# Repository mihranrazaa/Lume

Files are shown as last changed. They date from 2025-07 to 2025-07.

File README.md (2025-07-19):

# Lume

An Open Source alternative of Kindle which gives you freedom to download and read anything you want.

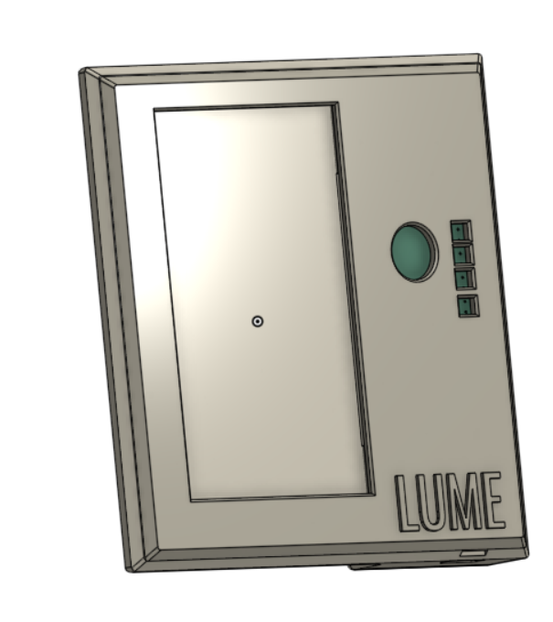
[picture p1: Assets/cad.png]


----

## Overview 

Lume is a open source eBook Reader made for people who value freedom, simplicity and are fed up by the limitations and companies not valuing ownership . With Lume, you're free to choose how you read and what you install.

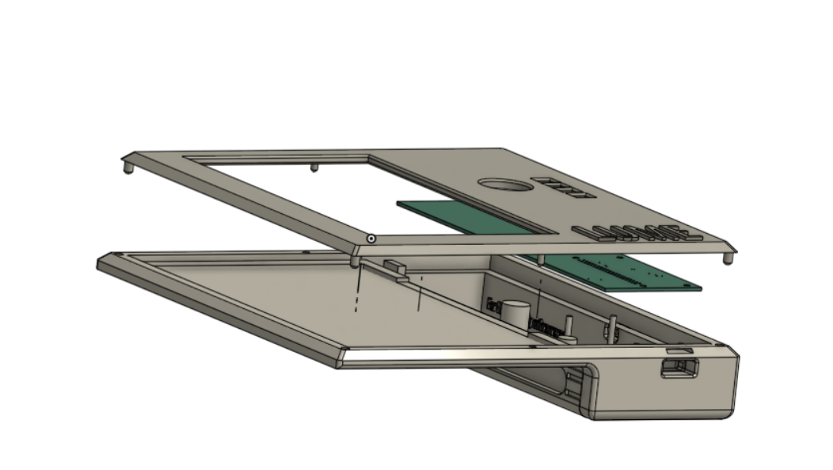
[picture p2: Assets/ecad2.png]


---

## Specifications
### Features(V0.1)

- Simple Menu System
- Bookmark System
- Joystick for smooth navigation
- Reading files ofc
- Offline-First
- approx1 week battery life (on medium usage)

### Hardware Support

- 7.5inch E-ink display
- Raspberry PI Zero 2w
- 5 way joystick navigation
- 4 Push buttons

### Controls

- **Joystick : Navigate menu items
- **Joystick : Turn pages while reading
- **Joystick : Select item
- **Button 1 : Return to menu
- **Button 2 : Back/Return to menu
- **Button 3 : Bookmark current page
- **Button 4 : Settings

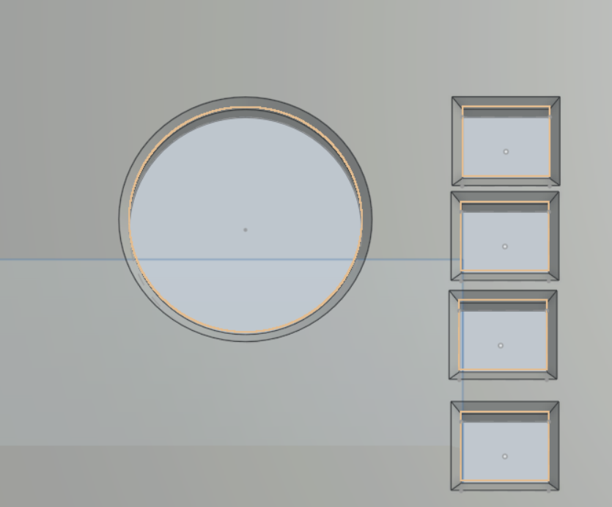
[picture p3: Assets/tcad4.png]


---
## Files to Build

### PCB

The files for the PCB and Schematics are available in the PCB folder and gerber files are added in the Production folder..

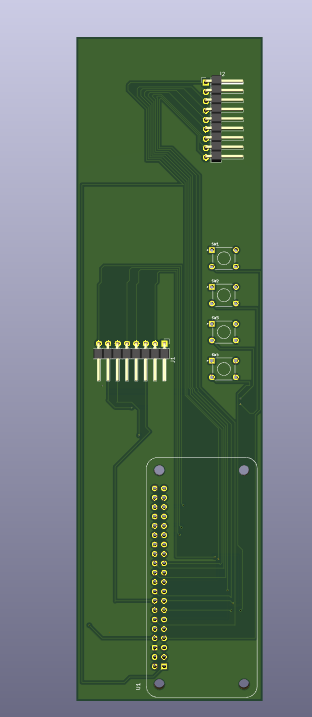
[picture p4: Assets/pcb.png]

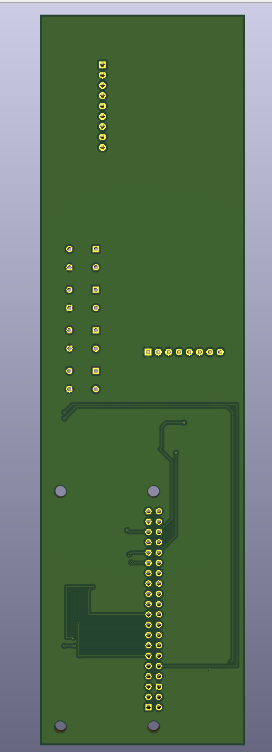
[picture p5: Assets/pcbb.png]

### 3D Case(CAD)

The step files for the keyboard are available in the CAD folder and also in the Production Folder.

**BASE**

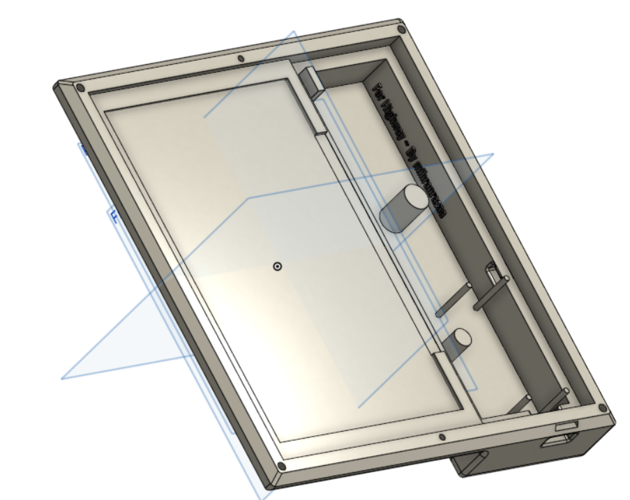
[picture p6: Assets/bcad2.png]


**PLATE**

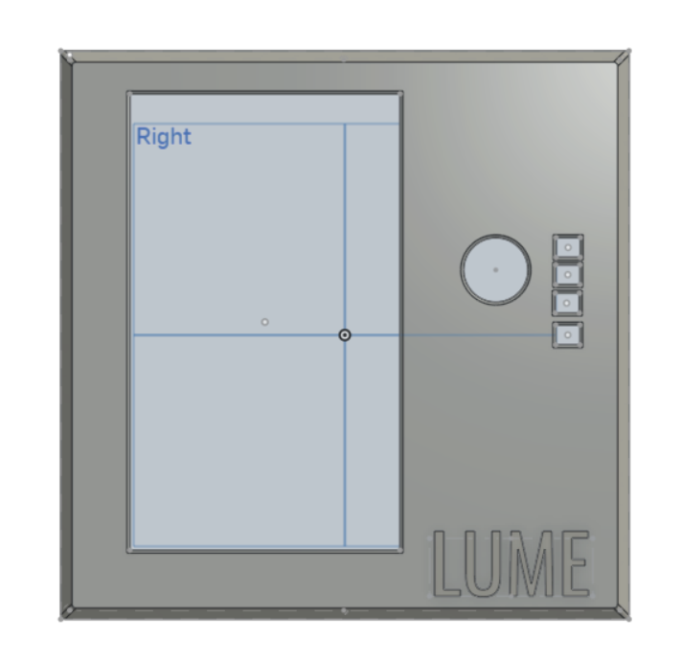
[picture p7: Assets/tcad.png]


---
## Images

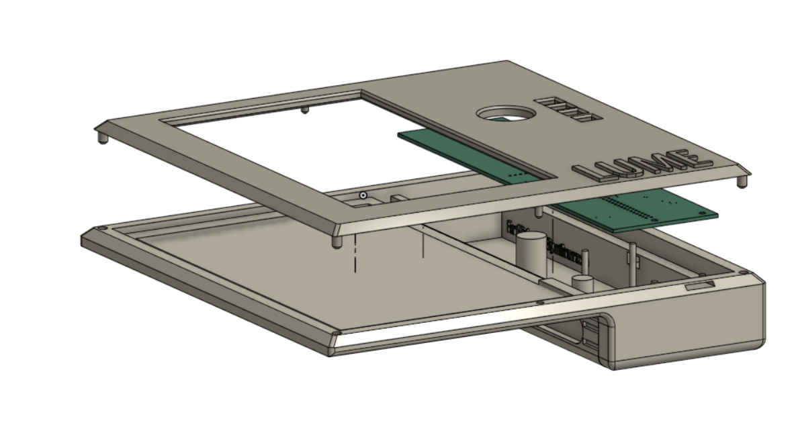
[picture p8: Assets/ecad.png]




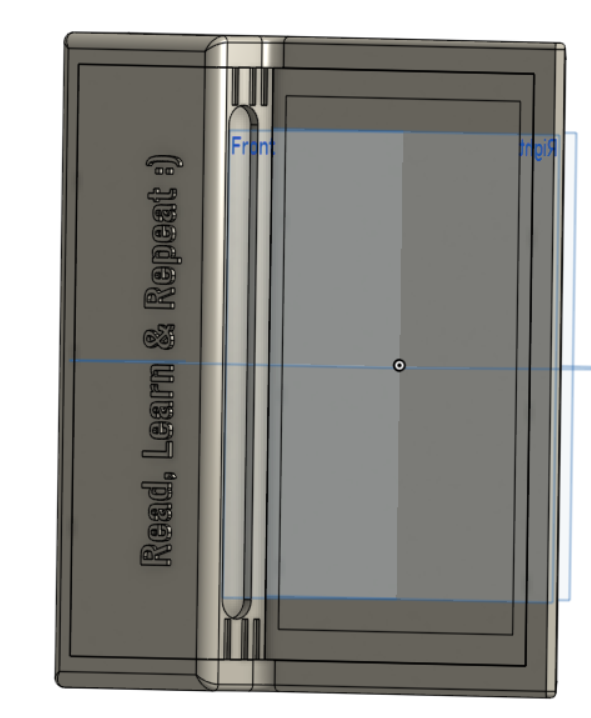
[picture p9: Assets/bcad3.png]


---
## BOM

| Components | Quantity | Price | Link |
| --- | --- | --- | --- |
| Raspberry pi zero 2w  | 1 | 16USD | [Available](https://www.fabtolab.com/raspberry-pi-zero-2-w-rp3a0-1ghz-quad-core-64-bit-arm-cortex-a53-cpu-512mb-sdram-wireless-lan-mini-hdmi-port-micro-usb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) |
| 7.5inch E-ink Display | 1 | 63USD | [Available](https://hubtronics.in/7-5-inch-e-paper-hat?search=7.5%20inch%20e%20ink%20) |
| 5D Joystick | 1 | 0.58USD | [Available](https://hubtronics.in/5d-rocker-joystick?search=joystick) |
| Tactile push buttons  | 4 | 0.28USD | |
| PCB | | approx10USD | |
| UPS | 1 | 27USD | [Available](https://hubtronics.in/ups-hat-c?search=ups%20hat%20) |
* Forgot to add an SD Card in there my bad

**Total ::  110-130USD**

---
## Next Update

- Add more support for different file types
- More Reading features
- Ability to transfer files via Wifi or Bluetooth 
- Progress bar

---
## Extra Stuff

### Gratitude
- Thanks to Hackclub for making me do this brilliant project, More coming :).
- Thanks to my potato for helping me till the end.
- Thanks to myself for completing the project and not getting distracted with another project.
- And Thank you for Reading?

### Inspiration
I always wanted a ebook reader and i was thinking of buying kindle but then got to know it's limitations so why not build my own :).

### Challanging
Building the custom case.. i don't have the words to express my pain...

---

## End
Check my [BLOG](https://mihranrazaa.pages.dev/)
~ mihranrazaa

BYEEE

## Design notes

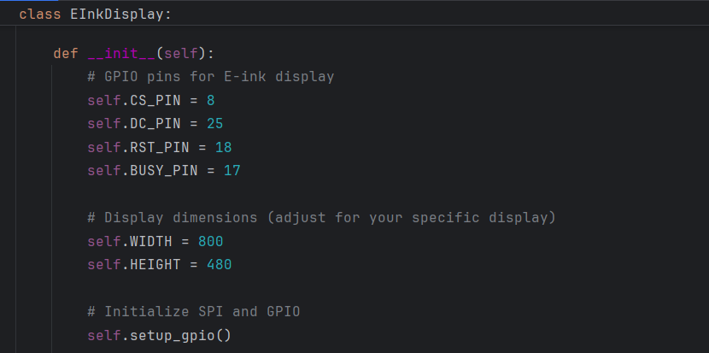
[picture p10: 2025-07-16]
Assets/code.png

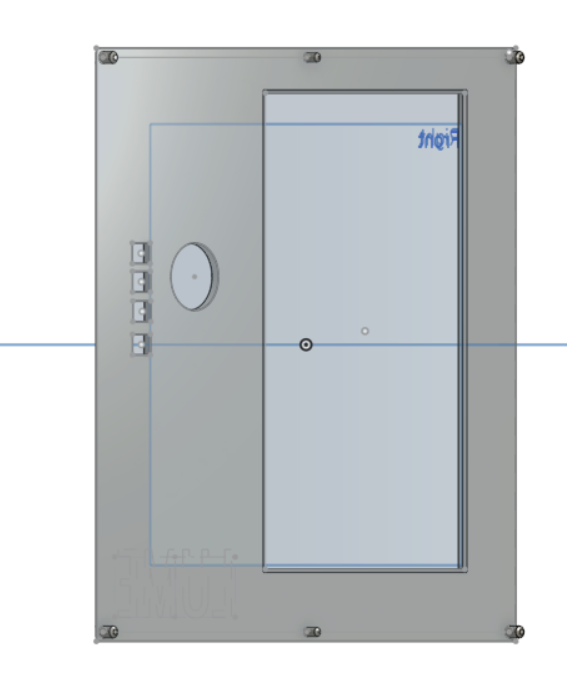
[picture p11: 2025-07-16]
Assets/tcad2.png

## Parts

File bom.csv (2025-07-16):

Designator | Footprint | Quantity | Value | LCSC Part #
J1 | PinHeader_1x08_P2.54mm_Horizontal | 1 | Conn_01x08
J2 | PinHeader_1x09_P2.54mm_Horizontal | 1 | Conn_01x09
SW1, SW2, SW3, SW4 | SW_1825910-6-43D | 4 | 1825910-6
U1 | MODULE_RASPBERRY_PI_ZERO_2_W | 1 | RASPBERRY_PI_ZERO_2_W

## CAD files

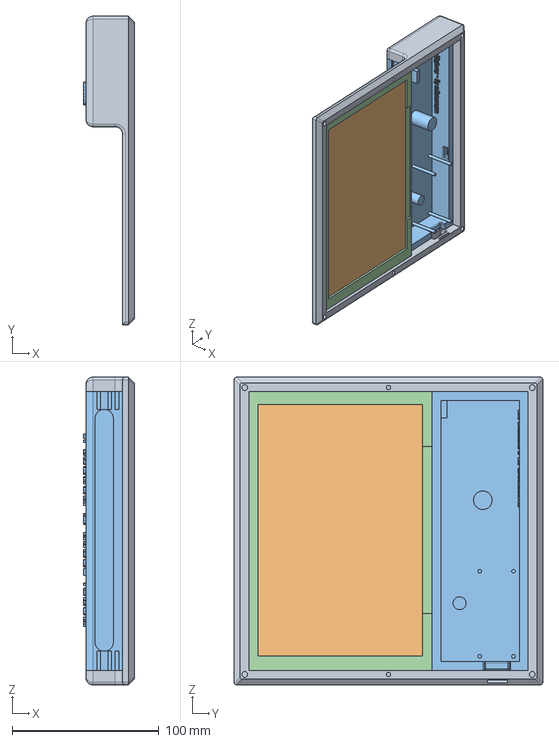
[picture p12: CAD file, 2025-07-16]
CAD/LUME-Base.step
34.5 x 210.5 x 210.0 mm

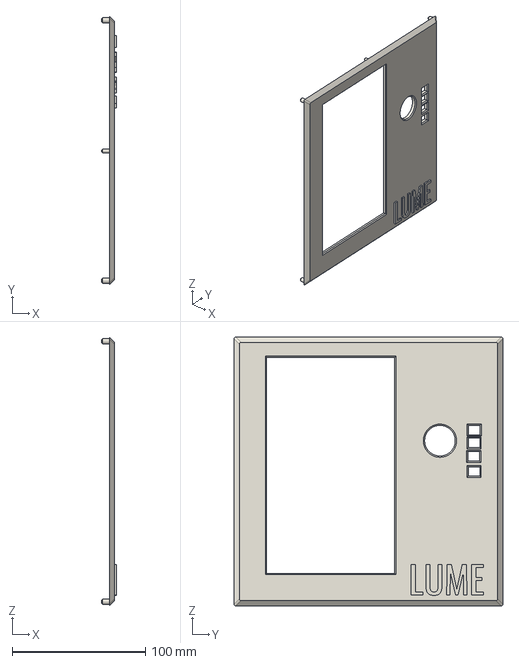
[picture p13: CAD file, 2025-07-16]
CAD/LUME-Top.step
11.5 x 201.7 x 201.7 mm

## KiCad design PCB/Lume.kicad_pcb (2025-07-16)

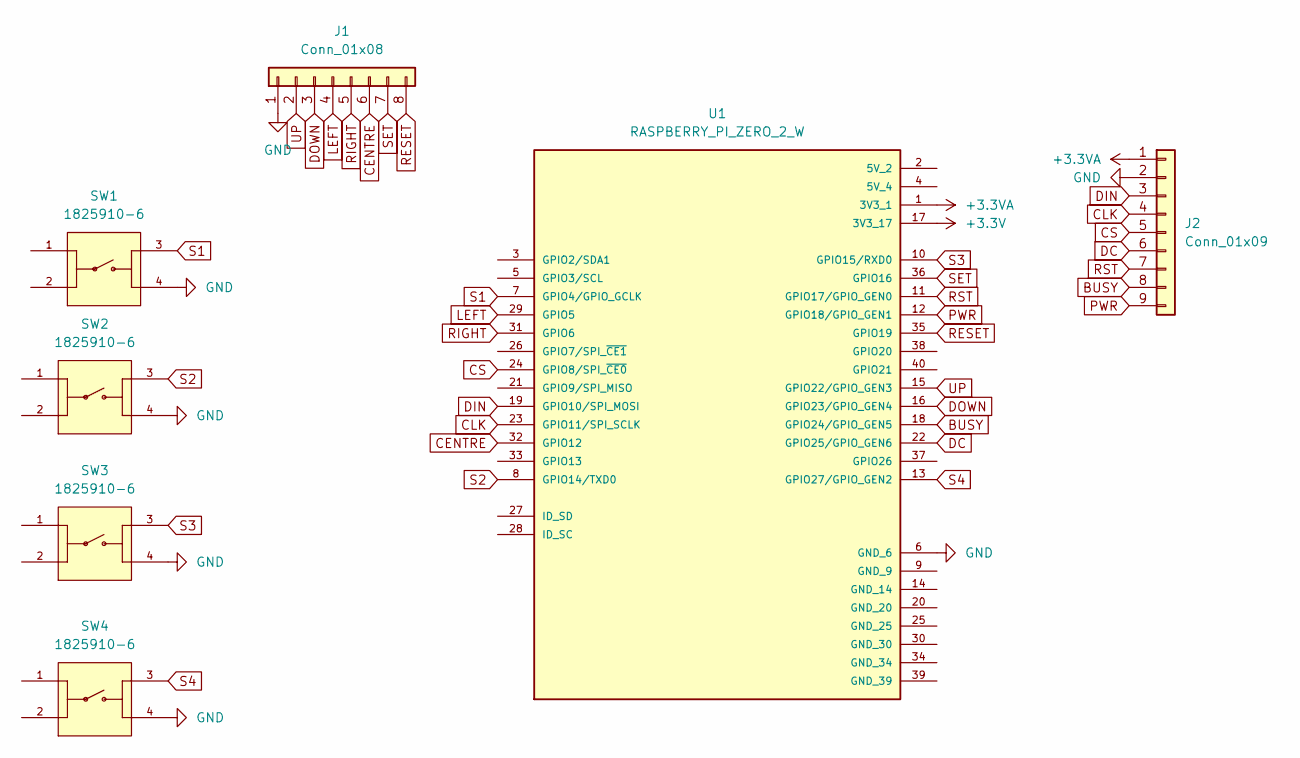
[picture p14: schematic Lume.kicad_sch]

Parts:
J1: Conn_01x08; PinHeader_1x08_P2.54mm_Horizontal
J2: Conn_01x09; PinHeader_1x09_P2.54mm_Horizontal
SW1, SW2, SW3, SW4: 1825910-6; SW_1825910-6-43D; PARTREV C10
U1: RASPBERRY_PI_ZERO_2_W; MODULE_RASPBERRY_PI_ZERO_2_W; PARTREV April 2024

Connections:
+3.3V: U1.17 (3V3_17)
+3.3VA: J2.1, U1.1 (3V3_1)
BUSY: J2.8, U1.18 (GPIO24/GPIO_GEN5)
CENTRE: J1.6, U1.32 (GPIO12)
CLK: J2.4, U1.23 (GPIO11/SPI_SCLK)
CS: J2.5, U1.24 (GPIO8/SPI_~CE0)
DC: J2.6, U1.22 (GPIO25/GPIO_GEN6)
DIN: J2.3, U1.19 (GPIO10/SPI_MOSI)
DOWN: J1.3, U1.16 (GPIO23/GPIO_GEN4)
GND: J1.1, J2.2, SW1.4, SW2.4, SW3.4, SW4.4, U1.6 (GND_6)
LEFT: J1.4, U1.29 (GPIO5)
PWR: J2.9, U1.12 (GPIO18/GPIO_GEN1)
RESET: J1.8, U1.35 (GPIO19)
RIGHT: J1.5, U1.31 (GPIO6)
RST: J2.7, U1.11 (GPIO17/GPIO_GEN0)
S1: SW1.3, U1.7 (GPIO4/GPIO_GCLK)
S2: SW2.3, U1.8 (GPIO14/TXD0)
S3: SW3.3, U1.10 (GPIO15/RXD0)
S4: SW4.3, U1.13 (GPIO27/GPIO_GEN2)
SET: J1.7, U1.36 (GPIO16)
UP: J1.2, U1.15 (GPIO22/GPIO_GEN3)

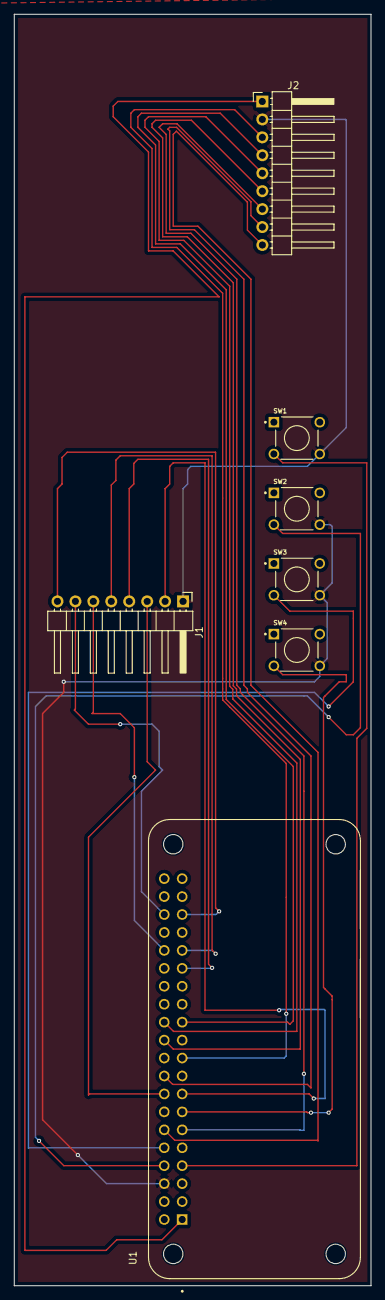
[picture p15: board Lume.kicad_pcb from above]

Board: 2 copper layers, 50.5 x 180.0 mm, 7 parts (0 on the bottom side), 20 nets.

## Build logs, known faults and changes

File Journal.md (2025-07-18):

---

title: "Lume"

author: "mihranrazaa"

description: "An Open Source alternative of Kindle "

created at: "2025-07-13"

---

----

**12 JULY**

- SO the plan is to build a alternative of kindle why? because from what i have seen on youtube, kindle can ban your account and your purchased books will be gone, sometimes when the deal between kindle and author of some book gets expired the books automatically vanishes from your account which is crazy, someone is paying full price but still he is not owning that piece, like it is not even a clooud service where subscription model is understandable.
- So yeah i thought to build a complete open source E book Reader "Lume" and this will be my first prototype...

---

**13 JULY**

- I have figured out my design i will make it, so today i first started by researching what components i will be using as i learnind in AMA if you are building a project which you want someone else to recreate use modules which is a good excuse to my lack of skills, so i selected Rpi zero 2w as my main MCU because it has wifi, blutooth and good support, i have a basic idea of what kind of software i want to build, so it is perfect for that, next i'm using 7.5inch e ink display with driver, vertically not horizontally which is giving more of real book page kind of vibe, then for inputs i first thought of five tactile push buttons for navigating and selecting but then i added a joystick and 4 tackile push buttons which will drastically improve user navigation as i'm building it for myself i think this will be a good choice so yeah also i will be using a battery hat for my pi zero 2w for poratbility ofc.....

- Alright so completed the schematics, i will be using 8pin cable to connect the driver to the main board, also i'm using 5D joystick because normal joystick module required ADC driver and i didn;t wanted to include it, and they both were same priced so i chose this, my idea of the CAD design is i can grab one side of the case with ease like it will be lifted from back and i will add pcb there, so yeah that works, now on to building pcb

- PCB DONEEE!!! so it is like a vertical strip, routing is good i have given adequate spacing for them so it should be fine, i enjoyed building this pcb lol, I've been working this whole day on this lol, i thought of this project yesterday and i now i have created it's PCB, Building is FUN. After coming back home i might start CAD let's see my plan is finishing this till 15th July....

- And yeah here are all the images:

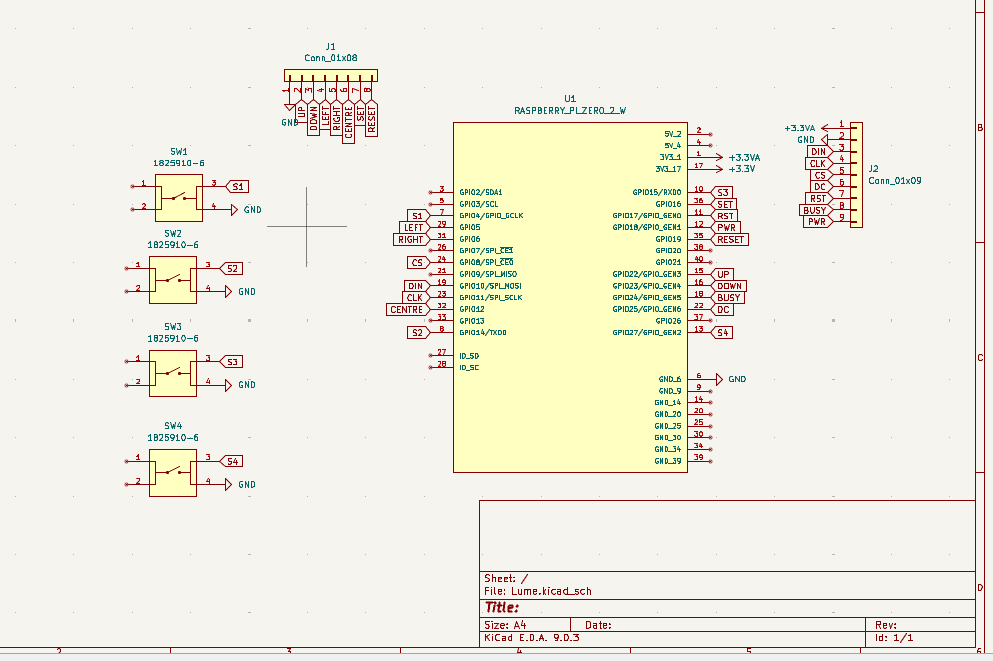
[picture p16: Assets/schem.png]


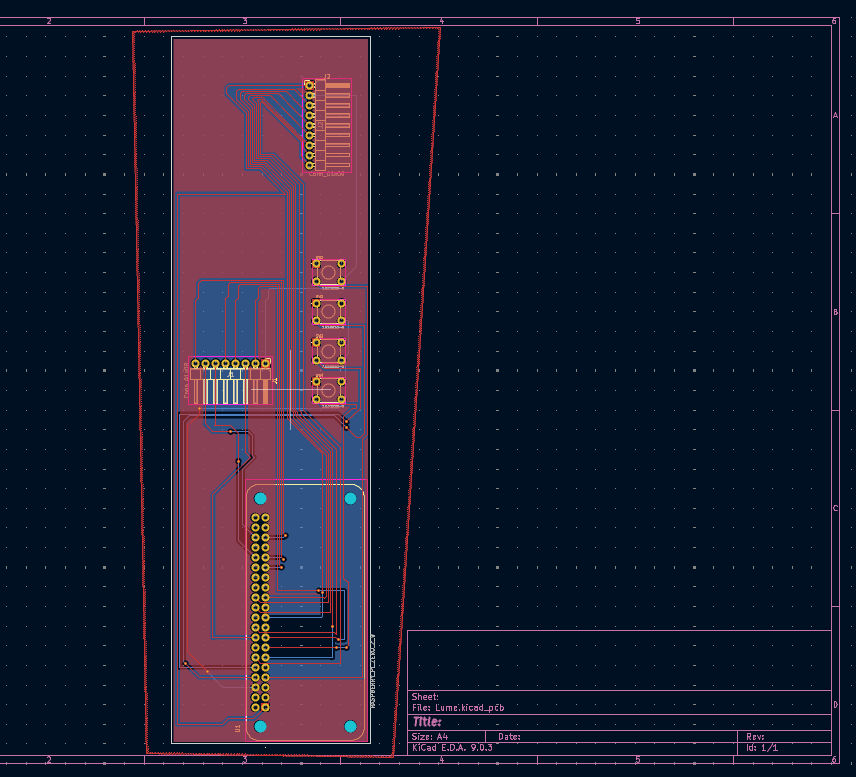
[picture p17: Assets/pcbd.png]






**Total 8Hrs+**

---

**14-15 JULY (CAD!!!!)**

- I forgot to write the Journal on 14th, i spent almost all day working on cad and didn't had energy to write journal lol, so this is the complete process of how i created my case.. I already had a basic idea in my mind, i didn't wanted to build a tab like reader so i searched some available reader and i found a very good concept basically there will be sleek display part and a elevated hardware part which will also work as grip to hold the reader, so i first start by taking mesurements of the display it is 7.5 inch display, so i already thought that i will rotat the display because it will look more like big book then that's why i created the pcb vertically rather then horizontal, so yeah,. That sums up the rough idea other things just came while doing it...

- I start by importing the pcb first to makesure the case fits in, i prefer to build over the components it give me confidence that the dimensions are coorect if i use a correct cad file lol, anyways then i created the rough sketch i first created them in one sketch but then i had to divide the base in 2-3 different parts as i'm noob and i was getting confused so it made easier to work with so i created the base extrusion nad basic stuff, then i started aligning and fixing the pcb place, i had to keep in mind that there will be a cable and driver board which will be connected in the pcb but there will also be wire from the display so i kept some gap so that wires can pass through, then i created the elevated part to which i used shell option in onshape, Then i thought becuase i was addding a grip olfring type thing why not add extrude inside where fingers will be placed for better grip, and it will also improve the look and it did!, so i added a cylindrical area in the elevated shell, then i added holes for my screwless design, i learned some more about snap fit designs and it is better to make the pins a bit bigger and add chaffer for enough friction, so i added 4mm and 3mm holes in the frame, Oh yeah i forgot to add that i added support for PCB and for pi zero 2 w and battery, then i started making it look good fixing small stuff checking dimensions, i added chaffer, fillet, also added more inside extrusion lines this time near the cylindrical holding area, then i added some writing in the case because why not.. Then i added 2 openings in the case, one for sd card and one for power, as i don't think it is needed any ports except power as there is only time that you have to add sd in pi zero and done filed will be uploaded via wifi or bluetooth, still because this is version 1 i did it anyways, with that my verision on ebase was ready and i moved to top...

- I started by taking dimensions of the main out frame i got confused a bit becuase of chaffer and fillet i was getting wrong dimensions i forgot about them then after realizing i fixed and it got write then added screen dimension and added input holes sketch oh yeah i forgot add thaat above anyways i put them in the correct place extruded the frame by 4-5mm then added chaffer and fillet, now when in assembly they are actually looking good, then i satrted taking dimesions of the holes and recreated that sketch in the the plate, added pin added chaffer, and pins were done, next i remved lume from back of base an added in the bottom of plate, after this the basic version was ready then i again touched up some parts and version 1 was ready.... checked if the pins are correctly ocnnecting or not and everything was fine, which leads us to right now i'm experimenting with colors i''m thinking of dark colour, and after this i have to start developing the code,i have to finish a alpha working code to ship it with the project i can work and improve the os with time...

- SO yeah that was the whole process of me building the case for Lume V1, ofc timelines are a bit different like not everything happend text by text i took breaks did other stuff returned worked on this and all, now i have to work on the code for this project, i have to shift the deadline to one more day, my previous goal was to ship the project on 15th july like a hackathon but it is isn't possible building the whole code in one day is not much possible for me i hope for the best....

- Here are all the images of building the CASE::

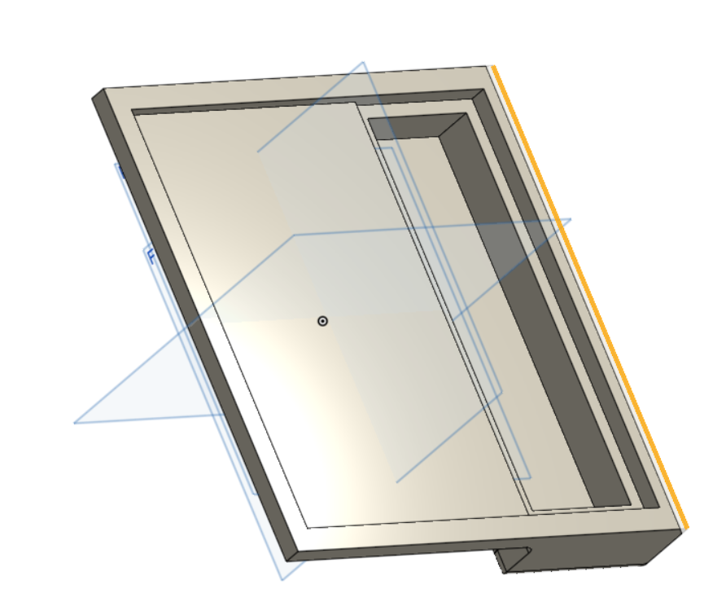
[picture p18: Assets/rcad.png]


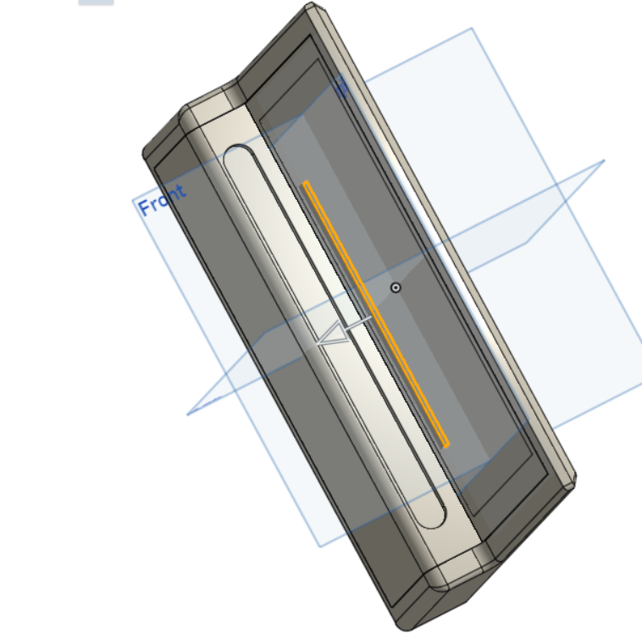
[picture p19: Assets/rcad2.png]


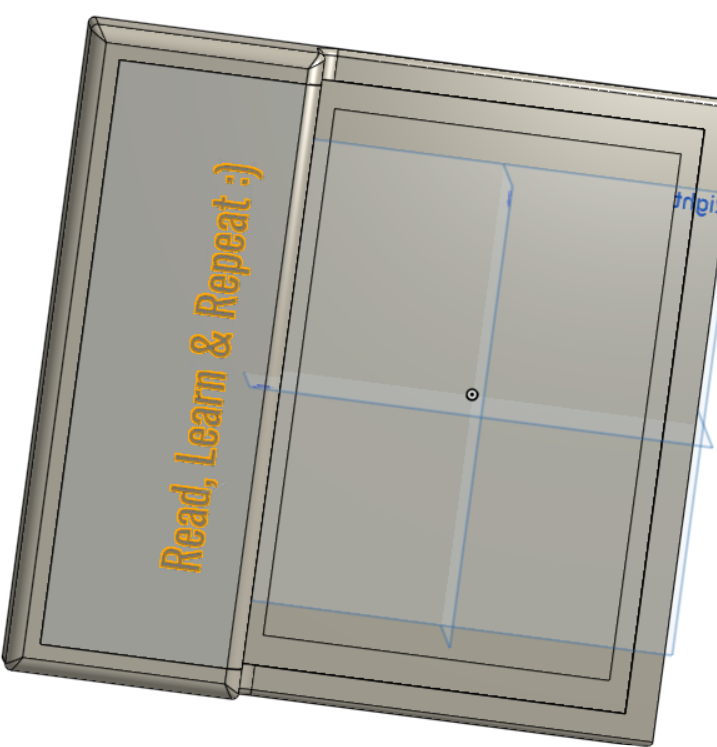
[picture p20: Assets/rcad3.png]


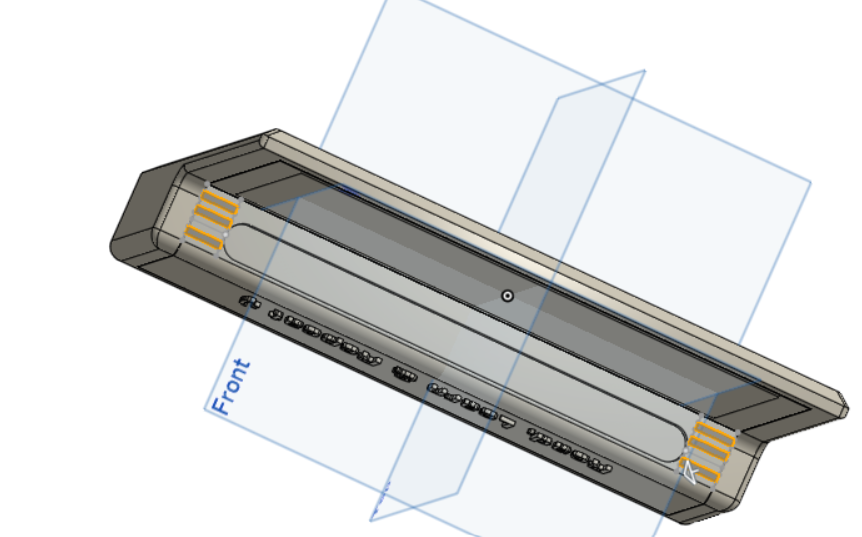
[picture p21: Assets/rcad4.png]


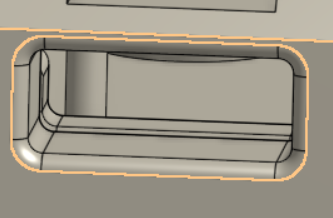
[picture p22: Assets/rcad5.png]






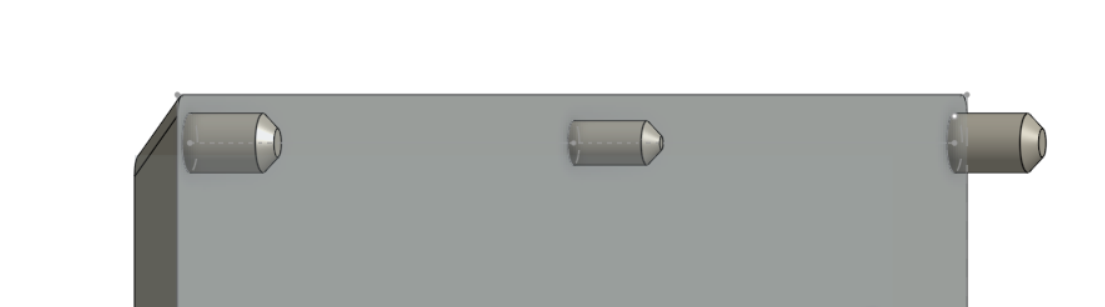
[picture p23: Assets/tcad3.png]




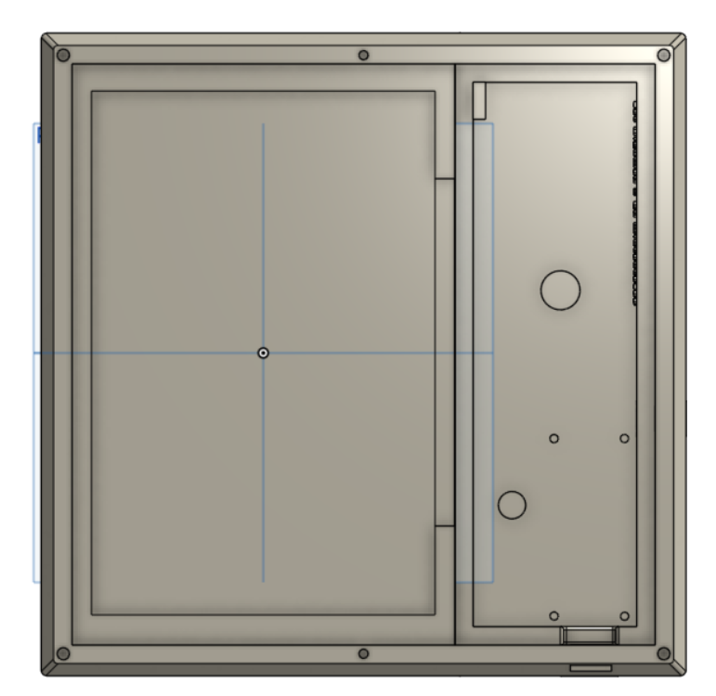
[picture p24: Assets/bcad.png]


- **Total 15Hrs+**

---
**JULY 15-16**

- Plan is to divide the code in 5 main classes, Screen control, Input handle, FIle manager and bookreader, i'm focusing on making it work firstly after core features i can improve upon...
- Started by COngfiguring GPIO Pins and SPI communication also i'm also thinking of making a installation script like i did in knobble, if i got some time after this it's easy anyways..
- Then i intialized eink display and crated a simple menu interface where selection will be highlighted.
- For input handling i did normal setup i also added debouncing to prevent multiple triggers. Mapped GPIO pins to event names
- then For book management, created function to refresh, list, and to get file path, to make my life easier.
-  then i started working on TExt processing and text pagination process, deinfed so that text can be displayed on the screen properly,
-  Then after all this i created another class which will work like orchestrator, tieing everything together, The main app has two main stated, main-while browsing file and reading- while reading books
- The application flow will be like first it will intialize display setup pins, and show menu
- then it will scan book directory, list them, and will handle navigation. After selectinig book it will paginate the text, nd resume from bookmark and from then it will handle page navigation update display, and save bookmark, currently i have only added .txt support but easily it can be extended because of the lib support python have "Thank God ToT" anyways this is the overall summarized process of me creating my own ebook reader i'm hella sleepy now after this i will add readme and will make it ready to submit....

**Total 9Hrs+**

---

- Making Readme and preparing for submission

----
**JULY 18**

- Added more support for file types epub, pdf..
- added more stuff in readme

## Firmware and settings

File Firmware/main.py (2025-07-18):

#!/usr/bin/env python3
"""
Lume an E-Reader for Raspberry Pi Zero 2W with E-ink Display
"""

import RPi.GPIO as GPIO
import time
import os
import json
import logging
from PIL import Image, ImageDraw, ImageFont
import threading
from pathlib import Path
import sys
import fitz  # PyMuPDF
from ebooklib import epub
from bs4 import BeautifulSoup

class BookReader:
    def display_page(self): pass
    def next_page(self): pass
    def prev_page(self): pass


class TextBookReader(BookReader):
    def __init__(self, file_path, display):
        self.file_path = file_path
        self.display = display
        self.current_page = 0
        self.pages = []
        self.chars_per_line = 80
        self.lines_per_page = 20
        self.load_book()

    def load_book(self):
        try:
            with open(self.file_path, 'r', encoding='utf-8') as f:
                content = f.read()
            lines = content.split('\n')
            current = []
            for line in lines:
                while len(line) > self.chars_per_line:
                    current.append(line[:self.chars_per_line])
                    line = line[self.chars_per_line:]
                current.append(line)
                if len(current) >= self.lines_per_page:
                    self.pages.append('\n'.join(current))
                    current = []
            if current:
                self.pages.append('\n'.join(current))
        except Exception as e:
            logging.error(f"Error loading TXT: {e}")
            self.pages = [f"Error loading book: {e}"]

    def display_page(self):
        if not self.pages: return
        self.display.buffer = Image.new('1', (self.display.WIDTH, self.display.HEIGHT), 1)
        y = 20
        for line in self.pages[self.current_page].split('\n'):
            self.display.draw_text(line, 10, y)
            y += 20
        self.display.draw_text(f"Page {self.current_page+1}/{len(self.pages)}", 10, self.display.HEIGHT - 25)
        self.display.display_image()

    def next_page(self):
        if self.current_page < len(self.pages) - 1:
            self.current_page += 1
            self.display_page()

    def prev_page(self):
        if self.current_page > 0:
            self.current_page -= 1
            self.display_page()


class PDFBookReader(BookReader):
    def __init__(self, file_path, display):
        self.display = display
        self.doc = fitz.open(file_path)
        self.current_page = 0
        self.total_pages = len(self.doc)

    def display_page(self):
        page = self.doc.load_page(self.current_page)
        pix = page.get_pixmap(matrix=fitz.Matrix(2, 2), alpha=False)
        image = Image.frombytes("RGB", [pix.width, pix.height], pix.samples)
        bw_image = image.convert("1").resize((self.display.WIDTH, self.display.HEIGHT))
        self.display.display_image(bw_image)

    def next_page(self):
        if self.current_page < self.total_pages - 1:
            self.current_page += 1
            self.display_page()

    def prev_page(self):
        if self.current_page > 0:
            self.current_page -= 1
            self.display_page()


class EPUBBookReader(BookReader):
    def __init__(self, file_path, display):
        self.display = display
        self.book = epub.read_epub(file_path)
        self.pages = []
        self.current_page = 0
        self.parse_book()

    def parse_book(self):
        for item in self.book.get_items():
            if item.get_type() == epub.ITEM_DOCUMENT:
                soup = BeautifulSoup(item.get_body_content(), 'html.parser')
                text = soup.get_text()
                self.pages.extend(self.paginate(text))

    def paginate(self, content):
        lines = content.split('\n')
        pages, current = [], []
        for line in lines:
            wrapped = [line[i:i+80] for i in range(0, len(line), 80)]
            for wline in wrapped:
                current.append(wline)
                if len(current) == 20:
                    pages.append('\n'.join(current))
                    current = []
        if current:
            pages.append('\n'.join(current))
        return pages

    def display_page(self):
        if not self.pages: return
        self.display.buffer = Image.new('1', (self.display.WIDTH, self.display.HEIGHT), 1)
        y = 20
        for line in self.pages[self.current_page].split('\n'):
            self.display.draw_text(line, 10, y)
            y += 20
        self.display.draw_text(f"Page {self.current_page+1}/{len(self.pages)}", 10, self.display.HEIGHT - 25)
        self.display.display_image()

    def next_page(self):
        if self.current_page < len(self.pages) - 1:
            self.current_page += 1
            self.display_page()

    def prev_page(self):
        if self.current_page > 0:
            self.current_page -= 1
            self.display_page()



    def open_book(self):
        file_path = self.file_manager.get_file_path(self.selected_index)
        if file_path is None:
            return
        try:
            ext = file_path.suffix.lower()
            if ext == '.txt':
                self.current_book = TextBookReader(file_path, self.display)
            elif ext == '.pdf':
                self.current_book = PDFBookReader(file_path, self.display)
            elif ext == '.epub':
                self.current_book = EPUBBookReader(file_path, self.display)
            else:
                logging.warning(f"Unsupported format: {ext}")
                return

            if str(file_path) == self.settings.get('last_book'):
                self.current_book.current_page = self.settings.get('last_page', 0)

            self.current_book.display_page()
            self.current_menu = 'reading'

            logging.info(f"Opened book: {file_path.name}")
        except Exception as e:
            logging.error(f"Error opening book: {e}")
